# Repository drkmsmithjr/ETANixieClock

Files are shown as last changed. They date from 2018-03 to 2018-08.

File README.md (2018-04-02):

# [Estimated Time of Arrival (ETA) Nixie Tube Clock](http://surfncircuits.com/2018/04/01/what-is-an-eta-nixie-tube-clock-and-how-do-you-build-one)
This DIY project will combine the estimated time of arrival function with a nixie tube display to create an estimated time of arrival (ETA) Nixie tube clock. It is all easily controlled by a Raspberry Pi Zero W that is connected to the internet through WiFi to provide the latest time and gets the ETA for any number of destinations. The travel time is provided by the free Google Directions API interface that includes traffic to give the best estimates on any particular day.   The goal is that with an ETA Nixie tube clock, no math is needed to add a rough, often optimistic travel time, to the actual time to determine if we are running late.   The clock does that for you and with the power of IOT, is much more accurate!    A motion sensor is also added to the clock to turn off the Nixie Tube Display when no one is around, saving power and increasing the nixie tube lifetime.    The complete project, including the six IN-4 Nixie tubes, are powered from a 1 amp iPhone charger using the 5v to 170v Nixie Tube Power supply described in another repository. 

See [www.surfncircuits.com](http://surfncircuits.com/2018/04/01/what-is-an-eta-nixie-tube-clock-and-how-do-you-build-one)  for a complete description.  This github repository contains the Kicad Schematic, Spice Simulation, Efficiency Calculations of the Estimated Time of Arrival (ETA) Nixie Tube Clock.   

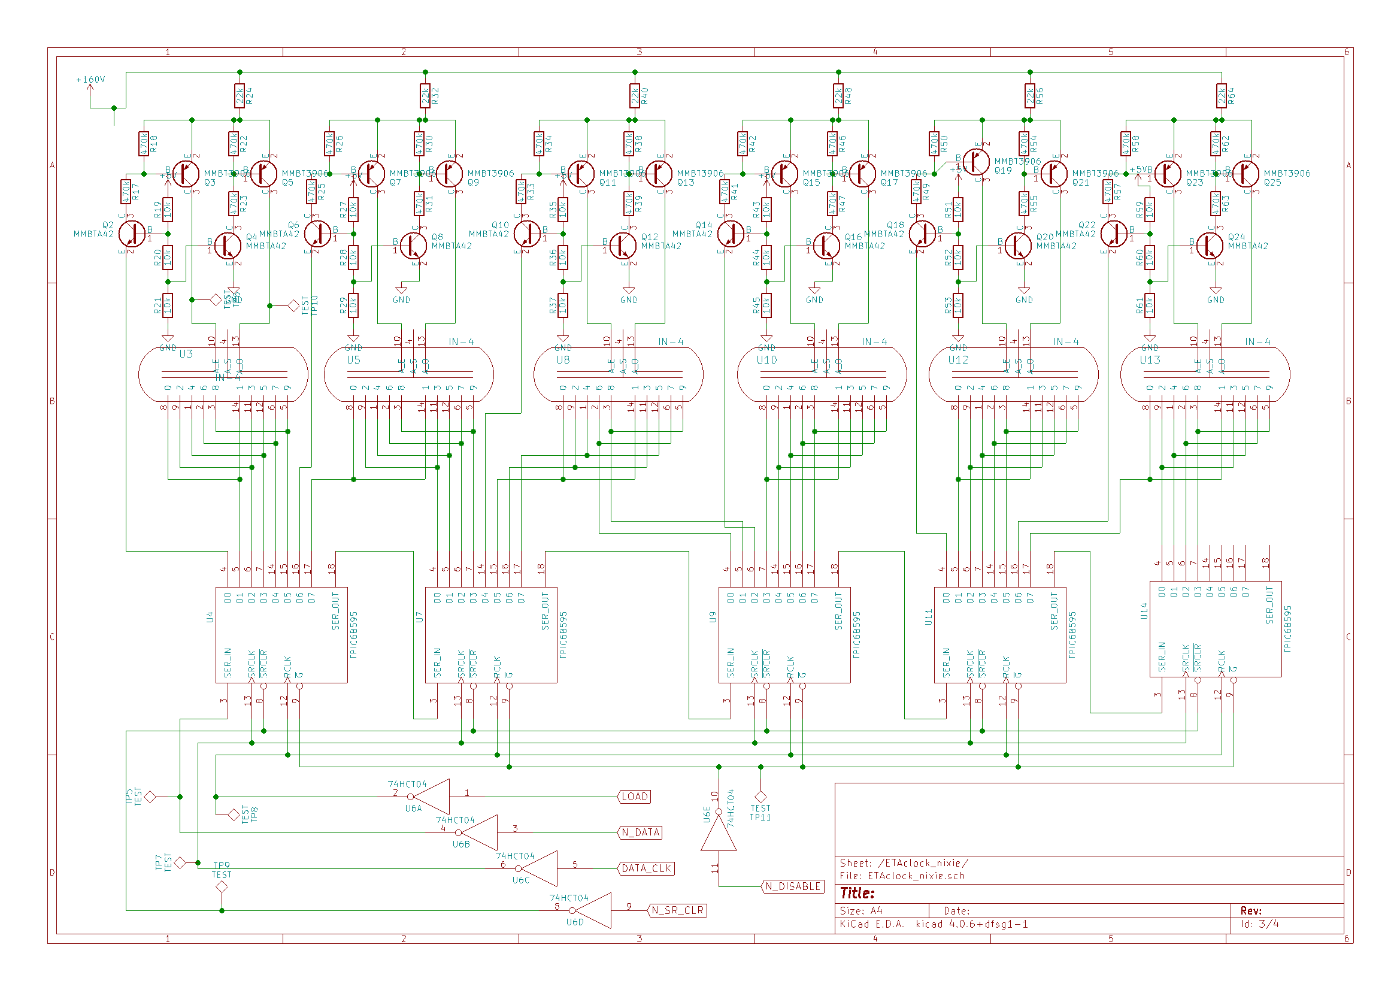
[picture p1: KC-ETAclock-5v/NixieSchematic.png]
PNG of the Schematic


__ETANixieCode__:  This is the python code that will be placed in the ETANixieClock directory on the Raspberry Pi zero.    

__KC_ETAclock-5v__:  KiCad schematic, PCB Layout, BOM of the ETA Nixie tube clock.  You can order the PCB from oshPark at   

__SimCalcFiles__:  Spice simulation files of the Nixie Tube bi-quinary driving circuit.    

__Datasheeets__: Datasheets for the pinout and the TPIC6B595.  In the Kicad Schematic, the part numbers and Digikey (TM) links are listed already.   Also the complete BOM is located in the KC-ETAclock-5v Directory (ETAclock_BOM.ods).      

See the complete blogs entry at  [www.surfncircuits.com](http://surfncircuits.com/2018/04/01/what-is-an-eta-nixie-tube-clock-and-how-do-you-build-one)

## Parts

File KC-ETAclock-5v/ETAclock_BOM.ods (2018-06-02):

Source: | /ETAclock.sch
Date: | Sat 03 Mar 2018 09:45:03 PM PST
Tool: | Eeschema 4.0.7-e2-6376~60~ubuntu17.10.1
Generator: | /usr/lib/kicad/plugins/bom_csv_grouped_by_value.py
Component Count: | 112
Collated Components:
Item | Qty | Reference(s) | Value | LibPart | Footprint | Datasheet | MPN
1 | 6 | C1, C2, C3, C4, C5, C6 | 0.1uF 250v | device:C | Capacitors_SMD:C_0805 | https://www.digikey.com/product-detail/en/tdk-corporation/CGA4J3X7T2E104M125AE/445-7965-1-ND/2782533 | CGA4J3X7T2E104M125AE
2 | 2 | C17, C19 | 47uF 10v | device:C | Capacitors_SMD:C_0805 | https://www.digikey.com/product-detail/en/taiyo-yuden/LMK212BBJ476MG-T/587-5465-1-ND/7067141 | LMK212BBJ476MG-T
3 | 6 | C23, C24, C25, C26, C27, C28 | 0.1uF | device:C | Capacitors_SMD:C_0805
4 | 6 | C29, C30, C31, C32, C33, C34 | 1uF | device:C | Capacitors_SMD:C_0805
5 | 4 | J1, J2, J3, J4 | Conn_01x01 | conn:Conn_01x01 | Mounting_Holes:MountingHole_2.2mm_M2_Pad
6 | 1 | J5 | USB_SUPPLY | ETAclock-rescue:USB_SUPPLY | etaclock:USB_SUPPLY_5v_TO_170v_MINI_2M
7 | 1 | J6 | Conn_01x05 | conn:Conn_01x05 | Pin_Headers:Pin_Header_Straight_1x05_Pitch2.54mm
8 | 1 | L1 | 60ohm 100Mhz | device:L | Resistors_SMD:R_0805 | https://www.digikey.com/product-detail/en/taiyo-yuden/BKP2125HS600-T/587-1932-1-ND/1465402 | BKP2125HS600-T
9 | 1 | P15 | Raspberry_PI_Zero_Hat | ETAclock-cache:Raspberry_PI_Zero_Hat | etaclock:R_Pi_Zero_40pins_No_Mount
10 | 12 | Q2, Q4, Q6, Q8, Q10, Q12, Q14, Q16, Q18, Q20, Q22, Q24 | MMBTA42 | transistors:MPSA42 | TO_SOT_Packages_SMD:SOT-23 | http://www.digikey.com/product-detail/en/micro-commercial-co/MMBTA42-TP/MMBTA42TPMSCT-ND/717401 | MMBTA42-TP
11 | 12 | Q3, Q5, Q7, Q9, Q11, Q13, Q15, Q17, Q19, Q21, Q23, Q25 | MMBTA92 | transistors:MPSA92 | TO_SOT_Packages_SMD:SOT-23 | http://www.digikey.com/product-detail/en/micro-commercial-co/MMBTA92-TP/MMBTA92-TPCT-ND/819693 | MMBTA92-TP
12 | 24 | R17, R18, R22, R23, R25, R26, R30, R31, R33, R34, R38, R39, R41, R42, R46, R47, R49, R50, R54, R55, R57, R58, R62, R63 | 470k | device:R | Resistors_SMD:R_0805
13 | 18 | R19, R20, R21, R27, R28, R29, R35, R36, R37, R43, R44, R45, R51, R52, R53, R59, R60, R61 | 10k | device:R | Resistors_SMD:R_0805
14 | 6 | R24, R32, R40, R48, R56, R64 | 22k | device:R | Resistors_SMD:R_0805
15 | 6 | U3, U5, U8, U10, U12, U13 | IN-4 | ETAclock-cache:IN-4 | etaclock:IN-4 | http://www.tube-tester.com/sites/nixie/data/in-4/in-4-sh1.htm
16 | 5 | U4, U7, U9, U11, U14 | TPIC6B595 | ETAclock-cache:TPIC5B595 | Housings_SOIC:SOIC-20W_7.5x12.8mm_Pitch1.27mm | http://www.digikey.com/product-detail/en/texas-instruments/TPIC6B595DWR/296-1351-1-ND/404964 | TPIC6B595DWR
17 | 1 | U6 | 74HCT04 | 74xx:74HCT04 | Housings_SOIC:SOIC-14_3.9x8.7mm_Pitch1.27mm | http://www.digikey.com/product-detail/en/fairchild-on-semiconductor/MM74HCT04MX/MM74HCT04MXCT-ND/965665 | MM74HCT04MX

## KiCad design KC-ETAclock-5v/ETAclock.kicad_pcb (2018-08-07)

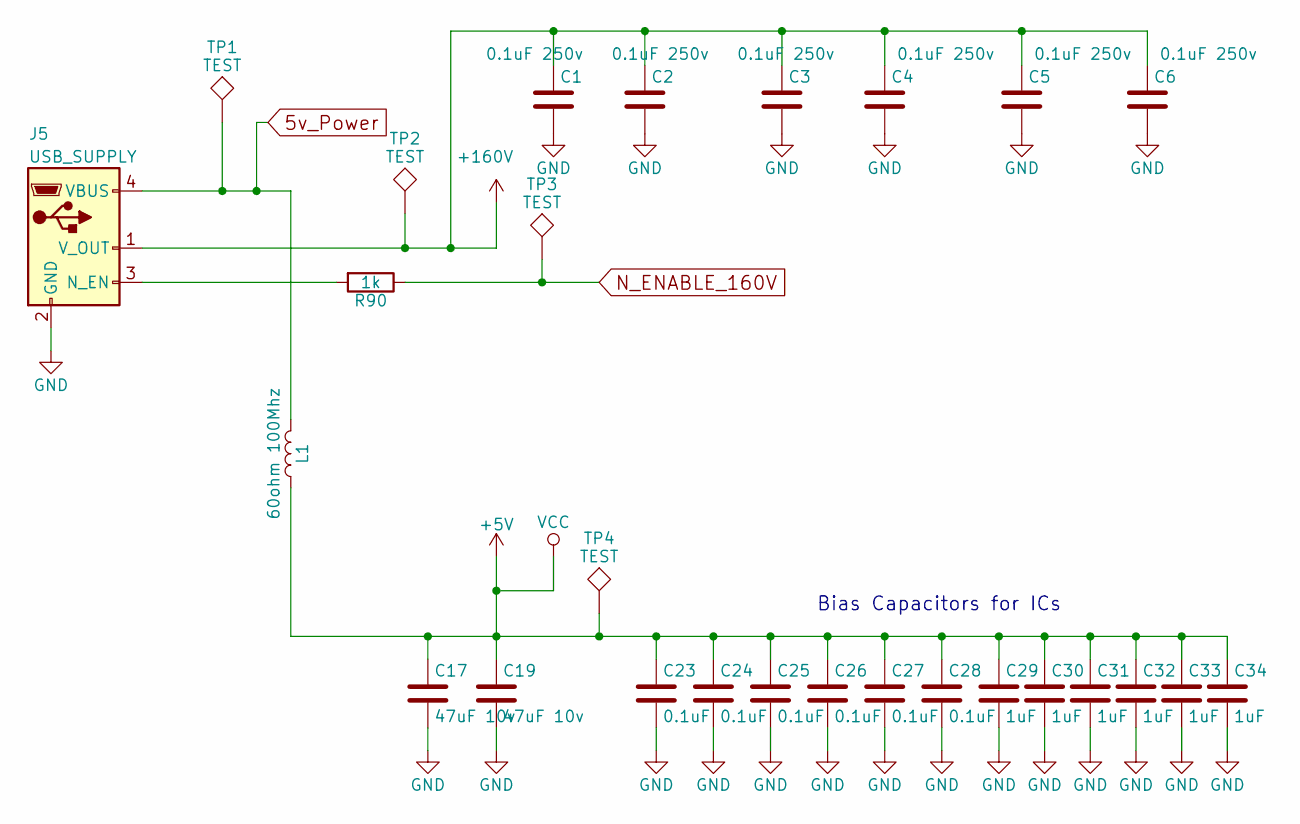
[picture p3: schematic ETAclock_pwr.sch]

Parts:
C1, C2, C3, C4, C5, C6: 0.1uF 250v; C_0805; MPN CGA4J3X7T2E104M125AE
C17, C19: 47uF 10v; C_0805; MPN LMK212BBJ476MG-T
C23, C24, C25, C26, C27, C28: 0.1uF; C_0805
C29, C30, C31, C32, C33, C34: 1uF; C_0805
J5: USB_SUPPLY; USB_SUPPLY_5v_TO_170v_MINI_2M
L1: 60ohm 100Mhz; R_0805; MPN BKP2125HS600-T
R90: 1k; R_0805
TP1, TP2, TP3, TP4: TEST; PINTST

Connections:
5v_Power: J5.4 (VBUS), L1.2, TP1.1
+5V: C17.1, C19.1, C23.1, C24.1, C25.1, C26.1, C27.1, C28.1, C29.1, C30.1, C31.1, C32.1, C33.1, C34.1, L1.1, TP4.1; also elsewhere on the board
+160V: C1.1, C2.1, C3.1, C4.1, C5.1, C6.1, J5.1 (V_OUT), TP2.1; also elsewhere on the board
GND: C1.2, C2.2, C3.2, C4.2, C5.2, C6.2, C17.2, C19.2, C23.2, C24.2, C25.2, C26.2, C27.2, C28.2, C29.2, C30.2, C31.2, C32.2, C33.2, C34.2, J5.2 (GND); also elsewhere on the board
N_ENABLE_160V: R90.1, TP3.1; also elsewhere on the board
unnamed: J5.3 (N_EN), R90.2

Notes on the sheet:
Bias Capacitors for ICs

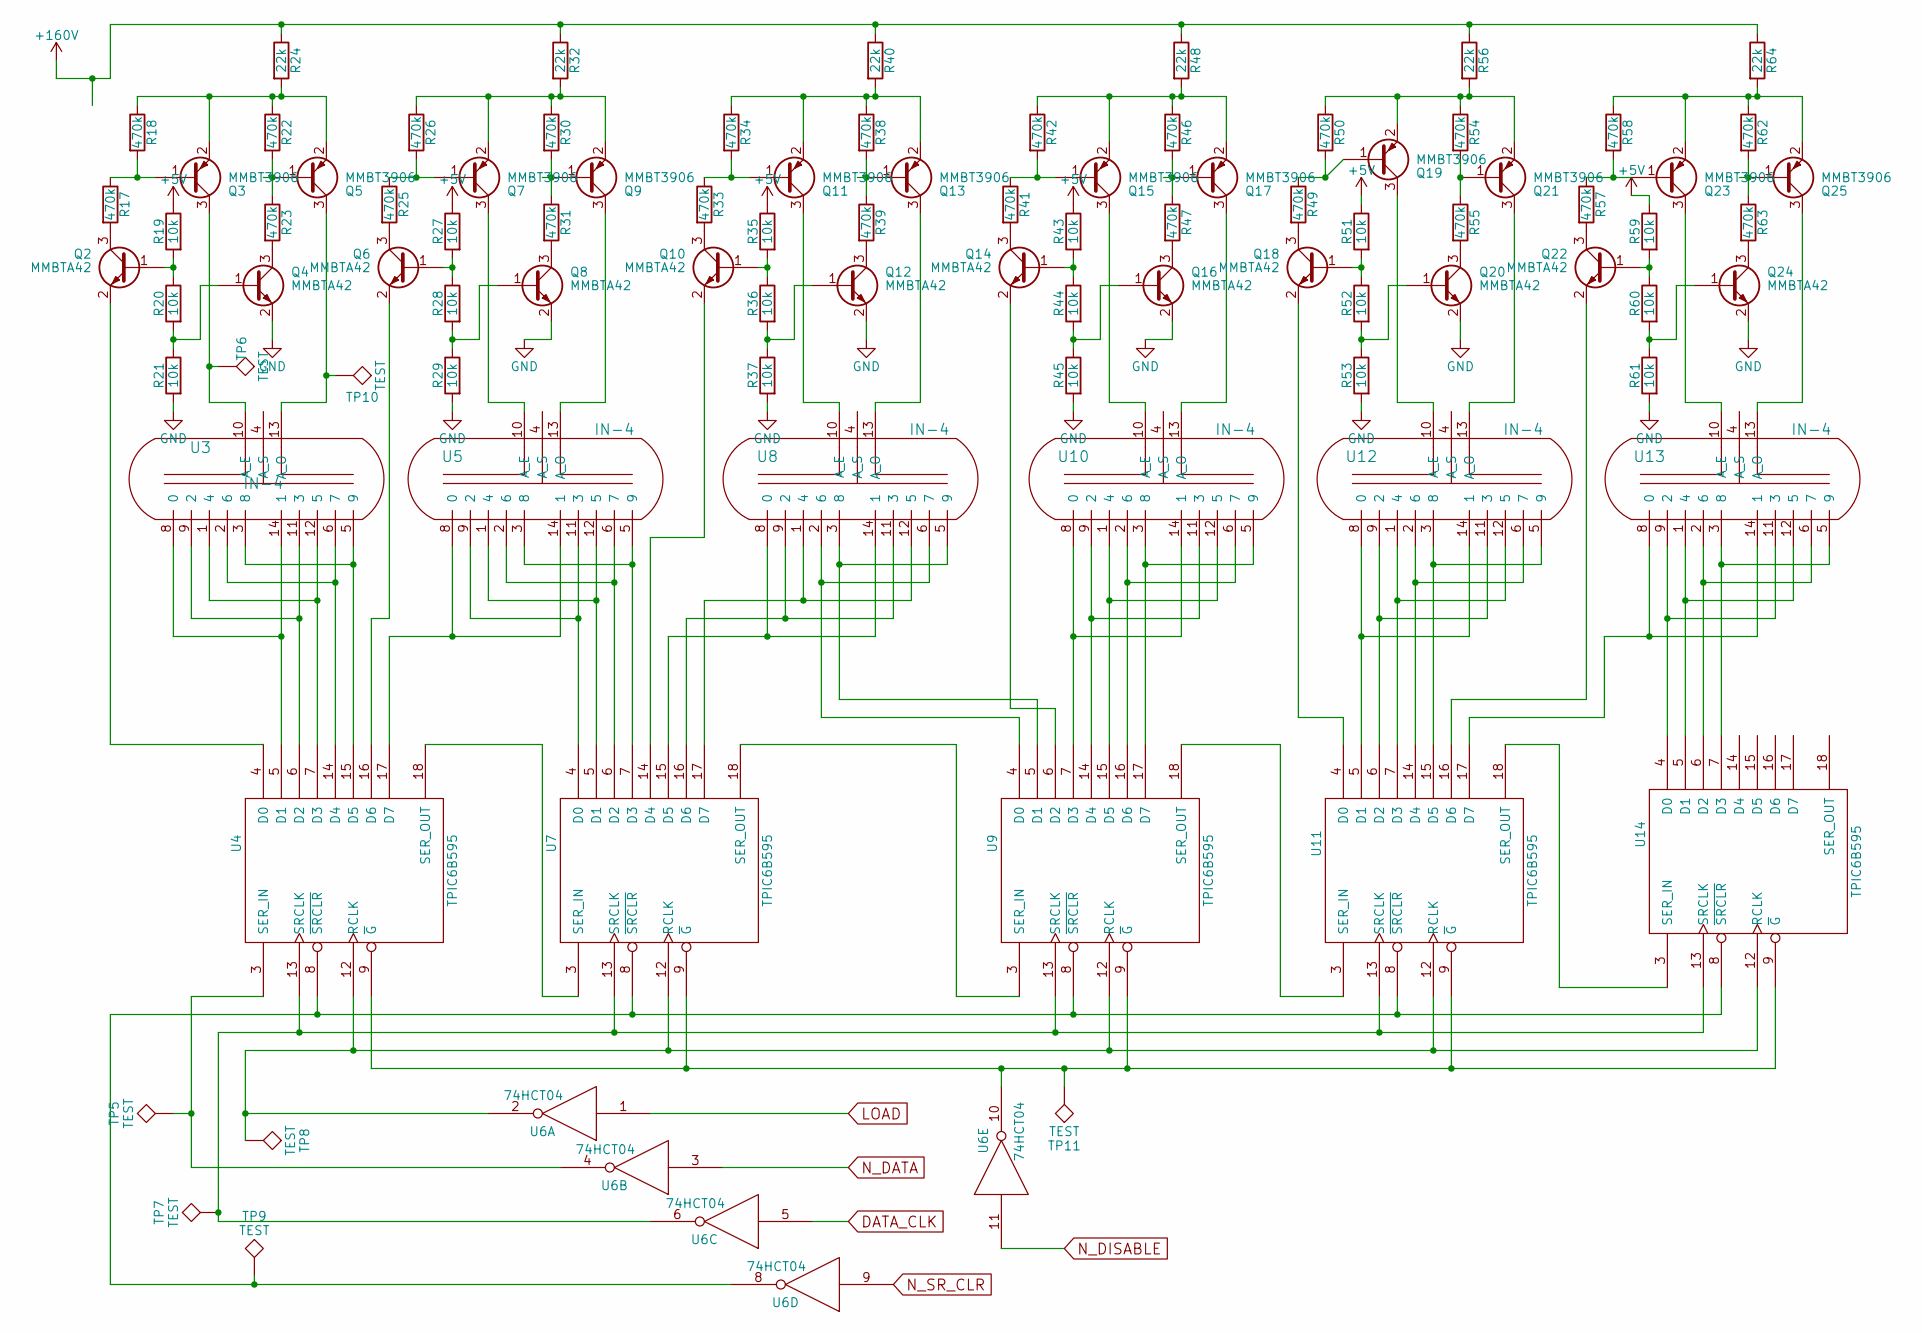
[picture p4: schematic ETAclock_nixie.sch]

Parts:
Q2, Q4, Q6, Q8, Q10, Q12, Q14, Q16, Q18, Q20, Q22, Q24: MMBTA42; SOT-23; MPN MMBTA42-TP
Q3, Q5, Q7, Q9, Q11, Q13, Q15, Q17, Q19, Q21, Q23, Q25: MMBT3906; SOT-23; MPN MMBTA92-TP
R17, R18, R22, R23, R25, R26, R30, R31, R33, R34, R38, R39, R41, R42, R46, R47, R49, R50, R54, R55, R57, R58, R62, R63: 470k; R_0805
R19, R20, R21, R27, R28, R29, R35, R36, R37, R43, R44, R45, R51, R52, R53, R59, R60, R61: 10k; R_0805
R24, R32, R40, R48, R56, R64: 22k; R_0805
TP5, TP6, TP7, TP8, TP9, TP10, TP11: TEST; PINTST
U3, U5, U8, U10, U12, U13: IN-4
U4, U7, U9, U11, U14: TPIC6B595; SOIC-20W_7.5x12.8mm_Pitch1.27mm; MPN TPIC6B595DWR
U6: 74HCT04; SOIC-14_3.9x8.7mm_Pitch1.27mm; MPN MM74HCT04MX

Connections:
+5V: R19.1, R27.1, R35.1, R43.1, R51.1, R59.1, U4.2 (VCC), U6.14 (VCC), U7.2 (VCC), U9.2 (VCC), U11.2 (VCC), U14.2 (VCC); also elsewhere on the board
+160V: R24.1, R32.1, R40.1, R48.1, R56.1, R64.1; also elsewhere on the board
DATA_CLK: U6.5; also elsewhere on the board
GND: Q4.2 (E), Q8.2 (E), Q12.2 (E), Q16.2 (E), Q20.2 (E), Q24.2 (E), R21.2, R29.2, R37.2, R45.2, R53.2, R61.2, U4.10 (GND), U4.11 (GND), U4.19 (GND), U6.7 (GND), U7.10 (GND), U7.11 (GND), U7.19 (GND), U9.10 (GND), U9.11 (GND), U9.19 (GND), U11.10 (GND), U11.11 (GND), U11.19 (GND), U14.10 (GND), U14.11 (GND), U14.19 (GND); also elsewhere on the board
LOAD: U6.1; also elsewhere on the board
N_DATA: U6.3; also elsewhere on the board
N_DISABLE: U6.11; also elsewhere on the board
N_SR_CLR: U6.9; also elsewhere on the board
unnamed: Q2.1 (B), R19.2, R20.1
unnamed: Q2.2 (E), U4.4 (D0)
unnamed: Q2.3 (C), R17.2
unnamed: Q3.1 (B), R17.1, R18.2
unnamed: Q3.2 (E), Q5.2 (E), R18.1, R22.1, R24.2
unnamed: Q3.3 (C), TP6.1, U3.10 (A_E)
unnamed: Q4.1 (B), R20.2, R21.1
unnamed: Q4.3 (C), R23.2
unnamed: Q5.1 (B), R22.2, R23.1
unnamed: Q5.3 (C), TP10.1, U3.13 (A_O)
unnamed: Q6.1 (B), R27.2, R28.1
unnamed: Q6.2 (E), U4.16 (D6)
unnamed: Q6.3 (C), R25.2
unnamed: Q7.1 (B), R25.1, R26.2
unnamed: Q7.2 (E), Q9.2 (E), R26.1, R30.1, R32.2
unnamed: Q7.3 (C), U5.10 (A_E)
unnamed: Q8.1 (B), R28.2, R29.1
unnamed: Q8.3 (C), R31.2
unnamed: Q9.1 (B), R30.2, R31.1
unnamed: Q9.3 (C), U5.13 (A_O)
unnamed: Q10.1 (B), R35.2, R36.1
unnamed: Q10.2 (E), U7.14 (D4)
unnamed: Q10.3 (C), R33.2
unnamed: Q11.1 (B), R33.1, R34.2
unnamed: Q11.2 (E), Q13.2 (E), R34.1, R38.1, R40.2
unnamed: Q11.3 (C), U8.10 (A_E)
unnamed: Q12.1 (B), R36.2, R37.1
unnamed: Q12.3 (C), R39.2
unnamed: Q13.1 (B), R38.2, R39.1
unnamed: Q13.3 (C), U8.13 (A_O)
unnamed: Q14.1 (B), R43.2, R44.1
unnamed: Q14.2 (E), U9.6 (D2)
unnamed: Q14.3 (C), R41.2
unnamed: Q15.1 (B), R41.1, R42.2
unnamed: Q15.2 (E), Q17.2 (E), R42.1, R46.1, R48.2
unnamed: Q15.3 (C), U10.10 (A_E)
unnamed: Q16.1 (B), R44.2, R45.1
unnamed: Q16.3 (C), R47.2
unnamed: Q17.1 (B), R46.2, R47.1
unnamed: Q17.3 (C), U10.13 (A_O)
unnamed: Q18.1 (B), R51.2, R52.1
unnamed: Q18.2 (E), U11.4 (D0)
unnamed: Q18.3 (C), R49.2
unnamed: Q19.1 (B), R49.1, R50.2
unnamed: Q19.2 (E), Q21.2 (E), R50.1, R54.1, R56.2
unnamed: Q19.3 (C), U12.10 (A_E)
unnamed: Q20.1 (B), R52.2, R53.1
unnamed: Q20.3 (C), R55.2
unnamed: Q21.1 (B), R54.2, R55.1
unnamed: Q21.3 (C), U12.13 (A_O)
unnamed: Q22.1 (B), R59.2, R60.1
unnamed: Q22.2 (E), U11.16 (D6)
unnamed: Q22.3 (C), R57.2
unnamed: Q23.1 (B), R57.1, R58.2
unnamed: Q23.2 (E), Q25.2 (E), R58.1, R62.1, R64.2
unnamed: Q23.3 (C), U13.10 (A_E)
unnamed: Q24.1 (B), R60.2, R61.1
unnamed: Q24.3 (C), R63.2
unnamed: Q25.1 (B), R62.2, R63.1
unnamed: Q25.3 (C), U13.13 (A_O)
unnamed: TP5.1, U4.3 (SER_IN), U6.4
unnamed: TP7.1, U4.13 (SRCLK), U6.6, U7.13 (SRCLK), U9.13 (SRCLK), U11.13 (SRCLK), U14.13 (SRCLK)
unnamed: TP8.1, U4.12 (RCLK), U6.2, U7.12 (RCLK), U9.12 (RCLK), U11.12 (RCLK), U14.12 (RCLK)
unnamed: TP9.1, U4.8 (~SRCLR), U6.8, U7.8 (~SRCLR), U9.8 (~SRCLR), U11.8 (~SRCLR), U14.8 (~SRCLR)
unnamed: TP11.1, U4.9 (~G), U6.10, U7.9 (~G), U9.9 (~G), U11.9 (~G), U14.9 (~G)
unnamed: U3.1 (4), U3.12 (5), U4.7 (D3)
unnamed: U3.2 (6), U3.6 (7), U4.14 (D4)
unnamed: U3.3 (8), U3.5 (9), U4.15 (D5)
unnamed: U3.9 (2), U3.11 (3), U4.6 (D2)
unnamed: U3.8 (0), U3.14 (1), U4.5 (D1)
unnamed: U4.17 (D7), U5.8 (0), U5.14 (1)
unnamed: U4.18 (SER_OUT), U7.3 (SER_IN)
unnamed: U5.1 (4), U5.12 (5), U7.5 (D1)
unnamed: U5.2 (6), U5.6 (7), U7.6 (D2)
unnamed: U5.3 (8), U5.5 (9), U7.7 (D3)
unnamed: U5.9 (2), U5.11 (3), U7.4 (D0)
unnamed: U7.15 (D5), U8.8 (0), U8.14 (1)
unnamed: U7.16 (D6), U8.9 (2), U8.11 (3)
unnamed: U7.17 (D7), U8.1 (4), U8.12 (5)
unnamed: U7.18 (SER_OUT), U9.3 (SER_IN)
unnamed: U8.2 (6), U8.6 (7), U9.4 (D0)
unnamed: U8.3 (8), U8.5 (9), U9.5 (D1)
unnamed: U9.15 (D5), U10.1 (4), U10.12 (5)
unnamed: U9.16 (D6), U10.2 (6), U10.6 (7)
unnamed: U9.17 (D7), U10.3 (8), U10.5 (9)
unnamed: U9.14 (D4), U10.9 (2), U10.11 (3)
unnamed: U9.7 (D3), U10.8 (0), U10.14 (1)
unnamed: U9.18 (SER_OUT), U11.3 (SER_IN)
unnamed: U11.5 (D1), U12.8 (0), U12.14 (1)
unnamed: U11.6 (D2), U12.9 (2), U12.11 (3)
unnamed: U11.7 (D3), U12.1 (4), U12.12 (5)
unnamed: U11.14 (D4), U12.2 (6), U12.6 (7)
unnamed: U11.15 (D5), U12.3 (8), U12.5 (9)
unnamed: U11.17 (D7), U13.8 (0), U13.14 (1)
unnamed: U11.18 (SER_OUT), U14.3 (SER_IN)
unnamed: U13.1 (4), U13.12 (5), U14.5 (D1)
unnamed: U13.2 (6), U13.6 (7), U14.6 (D2)
unnamed: U13.3 (8), U13.5 (9), U14.7 (D3)
unnamed: U13.9 (2), U13.11 (3), U14.4 (D0)

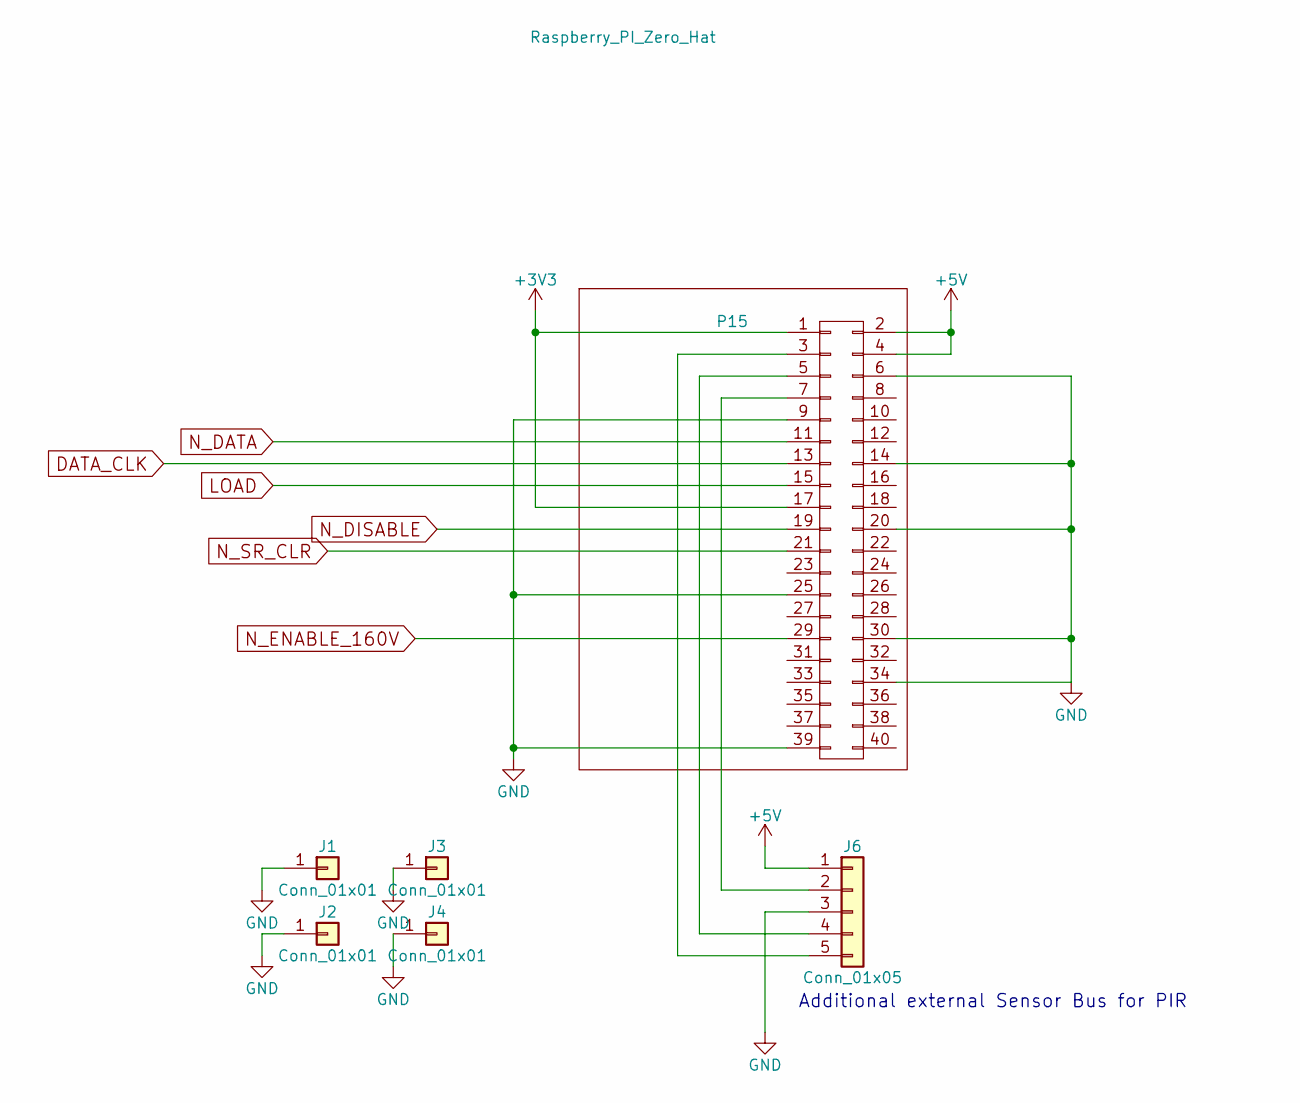
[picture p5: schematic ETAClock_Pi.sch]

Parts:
J1, J2, J3, J4: Conn_01x01; MountingHole_2.2mm_M2_Pad
J6: Conn_01x05; Pin_Header_Straight_1x05_Pitch2.54mm
P15: Raspberry_PI_Zero_Hat; R_Pi_Zero_40pins_No_Mount

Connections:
+3V3: P15.1, P15.17
+5V: J6.1, P15.2, P15.4; also elsewhere on the board
DATA_CLK: P15.13; also elsewhere on the board
GND: J1.1, J2.1, J3.1, J4.1, J6.3, P15.6, P15.9, P15.14, P15.20, P15.25, P15.30, P15.34, P15.39; also elsewhere on the board
LOAD: P15.15; also elsewhere on the board
N_DATA: P15.11; also elsewhere on the board
N_DISABLE: P15.19; also elsewhere on the board
N_ENABLE_160V: P15.29; also elsewhere on the board
N_SR_CLR: P15.21; also elsewhere on the board
unnamed: J6.2, P15.7
unnamed: J6.4, P15.5
unnamed: J6.5, P15.3

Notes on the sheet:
Additional external Sensor Bus for PIR

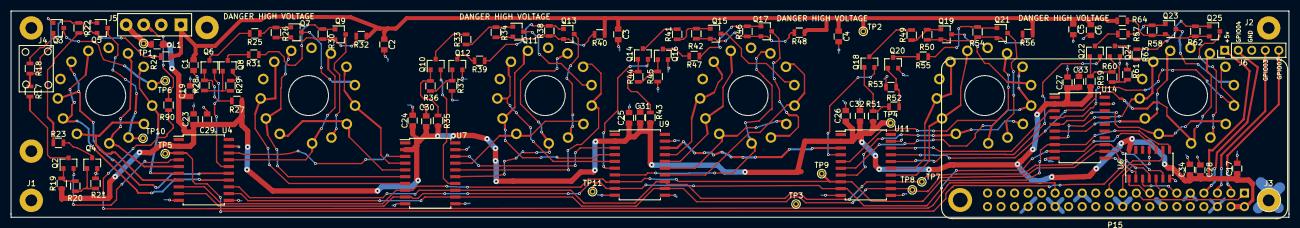
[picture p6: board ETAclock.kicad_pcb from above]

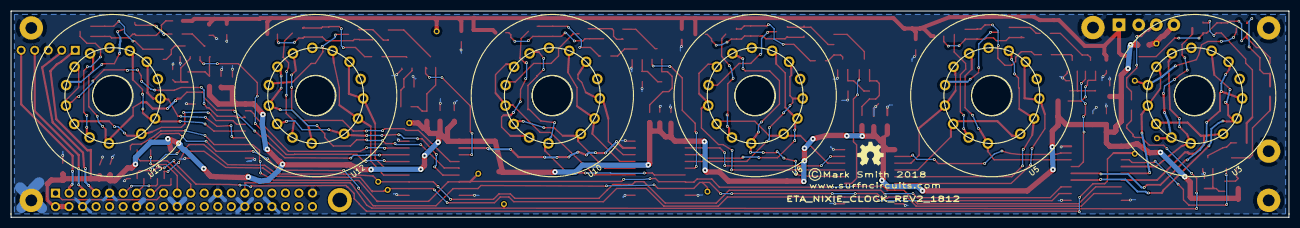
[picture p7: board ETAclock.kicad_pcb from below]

Board: 2 copper layers, 240.0 x 38.7 mm, 124 parts (6 on the bottom side), 114 nets.

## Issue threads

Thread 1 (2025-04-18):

Request

jet438, 2025-04-18:
Good Morning Mark: Sorry if this isn't the correct place to do this. I'm interested in this project on a number of levels. Very interested. I'm wanting to build a Nixie clock on an RPI base that serves as both a clock and a count down timer to a given day and time...namely retirement.. I'd like to do that utilizing In-12 tubes (because I already have them). I read your blog and noted the electrical difference between the Nixie you used and the ones I have. Unfortunately, my skills aren't in electrical schematic design or component choices. Those things are WAY out of my league. I'm a Civil Engineer...a "Grog make fire" kinda guy when it comes these type of things. That said, I can solder rather well and I do follow instructions extremely well.
In your blog you noted at one point that you were contemplating an additional schematic utilizing the In-14. Being very similar to the In-12 I'm curious as to whether you completed that design both on the schematic and python program levels since the registers (?) would have to change.
Anyway just wondering what or if there is an ETA for it.

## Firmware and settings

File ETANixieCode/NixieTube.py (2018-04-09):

#!/usr/bin/python
import RPi.GPIO as GPIO
import math
import time
import threading

# the tubes are architected to be a serial bit stream input.  
# the nixie type is for different types of Nixies

# BCM GPIP pin numbers being used 
N_DATA = 17
DATA_CLK = 27
LOAD = 22
N_DISABLE = 10
N_SR_CLR = 9
N_EN_PowerSupply = 5
PIR_SENSE=4


class NixieTube():

   def __init__(self,nixietype = 'IN-4', elements = 1 , PIR_SENSOR = False):
        self.nixietype = nixietype
        self.elements = elements
        # the displayed Digits to keep track of current state.  Initially empty
        # digits and StoredDigits will be a array of integers representing the digits to be displayed
        

        self.StoredDigits = []
        # the data that will be transferred to update the display
        self.SerialData = []
        for x in range (0,self.elements):
           self.StoredDigits.append(0)
        #setup GPIO to use the BCM numbering.  The adufruit extension shows the BCM 
        # BCM numbering
        GPIO.setmode(GPIO.BCM)   
        # set warnings false to avoid generating errors when the channel was set already
        GPIO.setwarnings(False)
        # intially set N_data high so data is low    
        GPIO.setup(N_DATA,GPIO.OUT, initial=GPIO.HIGH)
        # Data gets shifted in on the falling edge of DATA_CLK
        GPIO.setup(DATA_CLK,GPIO.OUT, initial=GPIO.LOW)
        # The LOAD will transfer shift registers to storge registers on falling edge of LOAD
        GPIO.setup(LOAD,GPIO.OUT , initial=GPIO.LOW)
        # NDISABLE: keeping this low will keep all outputs off on IC 
        self.DISPLAY_ON = False
        GPIO.setup(N_DISABLE,GPIO.OUT , initial=GPIO.LOW)
        # When Low shift registers are transferred to storage registers
        GPIO.setup(N_SR_CLR,GPIO.OUT , initial=GPIO.LOW)
        self.register_clear()
        # pulling low will ENABLE power supply
        self.POWER_ON = False
        GPIO.setup(N_EN_PowerSupply,GPIO.OUT , initial=GPIO.HIGH)
        # set the PIR_SENSE to an input and if the NixieTube has PIR_SENSOR..
        # PIR_SENSOR can also be used to turn on/off the PIR_SENSOR operation
        # Default of PIR_SENSOR is False
        # Default of the PIR_SENSE = True... ensure the clock will turn on
        self.PIR_SENSOR = PIR_SENSOR
        #self.PIR_SENSOR = True
        self.PIR_SENSE = True
        # PIR delay is in minutes
        self.PirDelay = 1
        GPIO.setup(PIR_SENSE,GPIO.IN)
        # define the sampling rate and delays for the PIR sensor in seconds 
        # the PIR sensor has a delay of 4 seconds.  so every 3 seconds will ensure to capture event
        self.PirSampling = 1
        self.CurrentDelay = 0
        # start the thread to sample the PIR Sensor
        self.PirSampleThread = threading.Thread(target = self.PirSample, args = (self.PirSampling,self.PirDelay))
        self.PirSampleThread.daemon = True 
        self.PirSampleThread.start()
              

   def PirSample(self,PirSampling,PirDelay):
        # this routine will run in a thread
        # if the PIR_SENSOR is On/ACTIVE, it will test the input
        # it will sample the PIR sensor every PirSampling rate
        # and it will update the PIR_SENSE boolean solution
        next_call = time.time()
        while self.PIR_SENSOR:
           #test PIR_SENSE input.
           self.CurrentDelay += PirSampling
           #print(self.CurrentDelay)
           if GPIO.input(PIR_SENSE):
              self.CurrentDelay = 0
           if self.CurrentDelay > (PirDelay*60):
              self.PIR_SENSE = False
              self.Power_Off()
              #clamp the currentDelay to max value
              self.CurrentDelay = PirDelay*60+1
           else:
              self.PIR_SENSE = True
           print(self.PIR_SENSE,self.CurrentDelay,GPIO.input(PIR_SENSE))
           next_call = next_call + PirSampling
           time.sleep(next_call - time.time())
                
   def digitsToSerial (self,digits,BlankCntrl = []):
        # this routine will conver the digits into the correct serial string.       
        # digits is an array that has at least # elemnts in it.
        # each digit will be converted into 6 serial bits.
        # bit 6 is even or odd (1 for even, 0 for odd)
        # the other 5 bits are zero except for the displayed digits
        # (ODD/EVEN BIT, 0-1,2-3,4-5,6-7, MSB = 8-9)
        # BlankCntrl is an optional parameter
        # that allows easy blanking of one digit in string
        # It will be an array of Booleans that correspond to the digits array
        # True for display, False for Blanking of that digit (not display)
        # for 12h time, the first digit is often not displayed.
        # test is BlankCntrl is empty, then default to display all 
        if len(BlankCntrl) == 0:
           for x in range (0, self.elements):
              BlankCntrl.append(True)       
        #Resetting serial data
        self.SerialData = []
        for x in range (0,self.elements):
           # find the digit numbering
           dignum = math.floor(digits[x]/2.0)
           # convert this into a power of two + 1  
           sdata = int(2**(dignum+1))
           # test to see if we should blank this displayed.  TRUE mean display digit 
           if BlankCntrl[x] == True:
              # bit wise OR with bin(64) or 7 sigit binary so we can perform bitwise ops
              sdata = sdata | 0b1000000
           else:
              #ensure all data is zero bits,2,3,4,5,6.   7th bit will be still even or odd and set.    
              sdata = 0b1000000
           # test for EVEN or ODD.  If EVEN, then LSB = 1
           if digits[x] % 2.0 == 0:
              sdata = sdata | 0b1
           # perform an exclusive or to get NDATA
           sdata = sdata ^ 0b111111
           strdata = bin(sdata)
           # now put the binary into array of 0 or 1 integers.  Ignore first 3 characters
           # these characters will be 0b1 from above
           for x in range (3,9):
              self.SerialData.append(int(strdata[x]))
        #print(self.SerialData)
        
   def ShiftData(self):
     # this will shift the SerialData into the serial registers
     # the data is loaded, then the data_clk goes high then low to clock in 
        for x in self.SerialData:
           GPIO.output(N_DATA, x)
           self.data_clock()
        GPIO.output(N_DATA,GPIO.HIGH)   
           
   def data_clock(self):
        GPIO.output(DATA_CLK,GPIO.HIGH)
        time.sleep(.001)         
        GPIO.output(DATA_CLK,GPIO.LOW)
        
   def LoadData(self):
        GPIO.output(LOAD,GPIO.HIGH)
        time.sleep(.001)         
        GPIO.output(LOAD,GPIO.LOW)  
        
   def register_clear(self):
        GPIO.output(N_SR_CLR,GPIO.HIGH)
        time.sleep(.001)         
        GPIO.output(N_SR_CLR,GPIO.LOW)
        
   def Display_On(self):
        if self.DISPLAY_ON == False:
           GPIO.output(N_DISABLE,GPIO.HIGH)
           self.DISPLAY_ON = True
   
   def Display_Off(self):
        if self.DISPLAY_ON:
           GPIO.output(N_DISABLE,GPIO.LOW)
           self.DISPLAY_ON = False
           time.sleep(.001)     

   def Power_On(self):
        if self.POWER_ON == False and self.PIR_SENSE:
        #if self.POWER_ON == False:
           GPIO.output(N_EN_PowerSupply,GPIO.LOW)
           self.POWER_ON = True 
           time.sleep(0.100)    

   def Power_On_Nodelay(self):
        if self.POWER_ON == False and self.PIR_SENSE:
        #if self.POWER_ON == False:
           GPIO.output(N_EN_PowerSupply,GPIO.LOW)
           self.POWER_ON = True 
           time.sleep(0.100)     
           
   def Power_Off(self):
        if self.POWER_ON:
           GPIO.output(N_EN_PowerSupply,GPIO.HIGH)
           self.POWER_ON = False
           time.sleep(.001)     

   def Write_Display(self, digits, BlankCntrl = []):
        self.Power_On()
        self.digitsToSerial(digits, BlankCntrl)
        self.register_clear()
        self.ShiftData()
        self.Display_Off()
        self.LoadData()
        self.Display_On()

   def Write_Display_No_Off(self, digits, BlankCntrl = []):
        self.Power_On()
        self.digitsToSerial(digits, BlankCntrl)
        self.register_clear()
        self.ShiftData()
        #self.Display_Off()
        self.LoadData()
        self.Display_On()
        self.StoredDigits = digits

   def Write_Spin_Digits(self, z, BlankCntrl = [], spin = 10):
        # Will take the current digits (z) and spin them in place for 
        # spin times .
        # there is a delay=2ms between displays
        # the total time for the spin is going to be write_display * spin.   
        delay = .002
        # power on the display if it is off.   
        self.Power_On()
        for y in range (0,spin):
          #increment z and reset to zero if reach 10
          for g in range (0,len(z)):
             z[g] += 1   
             if z[g] > 9:
                z[g] = 0
          self.Write_Display(z,BlankCntrl)
          time.sleep(delay)

   def Write_Spin_To_Digits(self, orig_digits, new_digits, orig_BlankCntrl = [], new_BlankCntrl = [], startspin = 5, transpin = 3):
        # Will take the current digits (z) and spin them in place and 
        # then start to display the new digits one at a time for number of total elements
        # the startspin is number of spins before starting
        # the transpins is the spins during transitions.
        # there is a delay=2ms between displays
        # the total time for the spin is going to be write_display * spin.   
        delay = .002
        # power on the display if it is off.   
        self.Power_On()

        orig_digitsCpy = list(orig_digits)
        orig_BlankCntrlCpy = list(orig_BlankCntrl)
        ind_digits = []
        ind_BlankCntrl = []

        # we need to use blank cntrl in this routine
        if orig_BlankCntrl == []:
           orig_BlankCntrlCpy = [True]*len(orig_BlankCntrl)

        if new_BlankCntrl == []:
           new_BlankCntrl = [True]*len(new_BlankCntrl)

        
        # spin then all now 
        for y in range (0,startspin):
          #increment z and reset to zero if reach 10
          for g in range (0,len(orig_digitsCpy)):
             orig_digitsCpy[g] += 1   
             if orig_digitsCpy[g] > 9:
                orig_digitsCpy[g] = 0
          self.Write_Display(orig_digitsCpy,orig_BlankCntrlCpy)
          time.sleep(delay)

        # now fix the first new digit and spin the rest of them
        for y in range(0,len(new_digits)):
          # add one to ind_digits
          # pop one from top of orig_digits
          ind_digits.append(new_digits[y])
          ind_BlankCntrl.append(new_BlankCntrl[y])
          orig_digitsCpy.pop(0)
          orig_BlankCntrlCpy.pop(0)
          # spin just the original digits fixing the rest
          for x in range (0,transpin):
          #increment z and reset to zero if reach 10
             for g in range (0,len(orig_digitsCpy)):
                orig_digitsCpy[g] += 1   
                if orig_digitsCpy[g] > 9:
                   orig_digitsCpy[g] = 0
             self.Write_Display(ind_digits+orig_digitsCpy,ind_BlankCntrl+orig_BlankCntrlCpy)
             time.sleep(delay)

          # update the ind_digits with the new BlankCntrl
          # now spin the original digits


   def Write_Fade_Out_Fade_In(self, digits, BlankCntrl = []):
        #print("digits into functions")
        #print(digits)
        self.Power_On()
        Tperiod = .0075   
        Cycles = 30
        #print(self.StoredDigits)
        #Fade OUt
        for x in range (0,Cycles):
           self.Display_On()
           time.sleep(Tperiod*(Cycles-x-1)/Cycles)
           self.digitsToSerial(self.StoredDigits, BlankCntrl)
           self.register_clear()
           self.ShiftData()
           self.LoadData()
           self.Display_Off()
           time.sleep(Tperiod*(x+1)/Cycles)
        #Fade In
        Cycles = 20
        for x in range (0,Cycles):
           self.Display_Off() 
           time.sleep(Tperiod*(Cycles-x-1)/Cycles)
           self.digitsToSerial(digits,BlankCntrl)
           self.register_clear()
           self.ShiftData()
           self.LoadData()
           self.Display_On()
           time.sleep(Tperiod*(x+1)/Cycles)
        self.digitsToSerial(digits, BlankCntrl)
        self.register_clear()
        self.ShiftData()
        self.LoadData()
        self.Display_On()
        self.StoredDigits = digits
        #print("stored digits")
        #print(digits)

   def Write_Fade_Out(self):
        # Fade_Out will take the StoredDigits and Fade it out.
        # Tperiod is the Period of on and off
        # cycles is how many cycles to make up the period.   
        # Tperiod*Cycles is the total transition time 
        self.Power_On()
        Tperiod = .0075   
        Cycles = 30
        print(self.StoredDigits)
        #Fade OUt
        for x in range (0,Cycles):
           self.Display_On()
           time.sleep(Tperiod*(Cycles-x-1)/Cycles)
           self.digitsToSerial(self.StoredDigits, BlankCntrl)
           self.register_clear()
           self.ShiftData()
           self.LoadData()
           self.Display_Off()
           time.sleep(Tperiod*(x+1)/Cycles)

   def Write_Fade_In(self, digits, BlankCntrl = []):
        # Fade_Out will take the StoredDigits and Fade it out.
        # Tperiod is the Period of on and off
        # cycles is how many cycles to make up the period.   
        # Tperiod*Cycles is the total transition time
        self.Power_On()
        Tperiod = .0075   
        Cycles = 20
        print(self.StoredDigits)
        #Fade OUt
        
        #Fade In
        for x in range (0,Cycles):
           self.Display_Off() 
           time.sleep(Tperiod*(Cycles-x-1)/Cycles)
           self.digitsToSerial(digits, BlankCntrl)
           self.register_clear()
           self.ShiftData()
           self.LoadData()
           self.Display_On()
           time.sleep(Tperiod*(x+1)/Cycles)
        self.digitsToSerial(digits, BlankCntrl)
        self.register_clear()
        self.ShiftData()
        self.LoadData()
        self.Display_On()
        self.StoredDigits = digits

   def Write_In_Fade_Out(self, digits, BlankCntrl = []):
        # Fade_Out will take the StoredDigits and Fade it out.
        # Tperiod is the Period of on and off
        # cycles is how many cycles to make up the period.   
        # Tperiod*Cycles1 + Tperiod*Cycles2 is the total transition time 
        self.Power_On()
        Tperiod = .0010   
        Cycles = 20
        print(self.StoredDigits)
        for x in range (0,Cycles):
           self.digitsToSerial(digits, BlankCntrl)
           self.register_clear()
           self.ShiftData()
           self.LoadData()
           self.Display_On()
           time.sleep(Tperiod*(x+1)/Cycles)
           self.digitsToSerial(self.StoredDigits,BlankCntrl)
           self.register_clear()
           self.ShiftData()
           self.LoadData()
           self.Display_On()
           time.sleep(Tperiod*(Cycles - x-1)/Cycles)
        self.digitsToSerial(digits, BlankCntrl)
        self.register_clear()
        self.ShiftData()
        self.LoadData()
        self.Display_On()
        self.StoredDigits = digits


   def Ramp_Display(self,digits, BlankCntrl = []):
   # turn on the nixie tube while ramping supply
        self.Power_Off()
        time.sleep(.125)
        self.digitsToSerial(digits, BlankCntrl)
        self.register_clear()
        self.ShiftData()
        self.Display_Off()
        self.LoadData()
        self.Display_On()
        for x in range(0,10):
           self.Power_On_Nodelay()
           time.sleep(.02)
           self.Power_Off
           time.sleep(.01)
        self.Power_On_Nodelay()
        time.sleep(.05)
        self.StoredDigits = digits
        
   def Pir_Sensor_On(self):
        self.PIR_SENSOR = True    
   
   def Pir_Sensor_Off(self):
        self.PIR_SENSOR = False

   def Pir_Delay_set(self,minutes):
        self.PirDelay = minutes    

  
if __name__ == "__main__":
        print "hello world"
       
        x = NixieTube()
        #x.Power_On()
        #for y in range (0,10):
        #   x.digitsToSerial([y])
        #   print(y,x.SerialData)
        #   x.ShiftData()
        #for y in range (0,10):
        #   x.data_clock()
        #for y in range (0,10):
        #   x.LoadData()
        #for y in range (0,10):
        #   x.register_clear()
        #for y in range (0,10):
        #   x.Display_On()
        #   x.Display_Off()
        #x.Write_Display([8])
        #time.sleep(0.5)
        #x.Write_Display([9])
        #time.sleep(0.5)       
        #x.Display_Off()
        y = 0
        z = 0

        while True:
           z += 1
           try:
              time.sleep(.02)
              x.Write_Display([y])
              y += 1
              if y > 9:
                  y = 0
              if z > 200:
                  break 
           except:
              time.sleep(0.2)
              x.Display_Off()
        x.Display_Off()
        x.Power_Off()
        

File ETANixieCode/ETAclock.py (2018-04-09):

#!/usr/bin/python

from locations import dest,orig
from googlemapsclientkey import clientkey
import NixieTube

import googlemaps
import datetime 
import math

import time
from time import sleep
from threading import Timer

# this timer will sychronize to system time time.time().   Great for clocks
class RepeatedSyncTimer(object):
  def __init__(self, interval ,function, *args, **kwargs):
    self._timer = None
    self.interval = interval
    self.function = function
    self.args = args
    self.kwargs = kwargs
    self.is_running = False
    self.error = 0.0
    # set this so that the interval is at 50% 0f a second, for clock to update
    # only needed if we have seconds
    self.next_call = math.ceil(time.time()) + 0.5
    self.start()

  def _run(self):
    self.is_running = False
    self.start()
    self.function(*self.args,**self.kwargs)

  def start(self):
    if not self.is_running:
      #syncronize the interval to 50% to allow to account for errors in the timer.
      #the timer interval is adjusted to sychronize with real time.  
      # this is important for clocks.  Above this was set at 50% of the interval
      self.next_call += self.interval
      self._timer = Timer(self.next_call - time.time(), self._run)
      self._timer.start()
      self.is_running = True

  def stop(self):
    self._timer.cancel()
    self.is_running = False

# in this algorithm.  print the time first, followed by each of the destinations 
# in the Array in order.

def PrtTime(timestr):
    global ind
    global TravelDuration
    global dest
    global TravelDurText
    # transtime determine how long in seconds to display the current ETA or Current time.  
    transtime = 5
    now = datetime.datetime.now()
    seconds = int(now.strftime("%S"))
    seconds = seconds % 10
    DigitSec.Write_Display([seconds])
    #print(seconds)
    # use the mod command to loop through all the destinations and print one at a time. 
    # we can use other functions and sequences to follow different activities.  
    ind2 = int(math.floor(ind/transtime))
    if ind2 >= len(dest):
       print(str(now)+ " " +  "The Current Time " + str(now))
       ind += 1
       if ind2 > len(dest):
          ind = 0
    else:
       ETA = now + datetime.timedelta(seconds=TravelDuration[ind2]) + datetime.timedelta(minutes=ETDdelay)
       print(str(now) + " "+ dest[ind2]['toplace'] + " " + str(ETA) + " Travel Time: " + TravelDurText[ind2])
       ind += 1

def PrtCurrentTimeOneNixie(timestr):
    global ind
    global TravelDuration
    global dest
    global TravelDurText
    # transtime determine how long in seconds to display the current ETA or Current time.  
    now = datetime.datetime.now()
    seconds_1digit = int(now.strftime("%S"))
    seconds_1digit = seconds_1digit % 10
    #DigitSec.Write_Display([seconds_1digit])
    Hour = int(now.strftime("%I"))
    Hour_1digit = int(math.floor(Hour/10.0))
    Hour_2digit = Hour % 10  
    Minute = int(now.strftime("%M"))
    Minute_1digit = int(math.floor(Minute/10.0))
    Minute_2digit = Minute % 10
    time_digits= [Hour_1digit,Hour_2digit,Minute_1digit,Minute_2digit]
    # test is we have twenty four hour time
    
    if ind > 4:
       ind = 0
    if ind == 4:
       z = time_digits[3]
       #DigitSec.Write_Fade_Out()
       time.sleep(.05)
       for y in range (0,10):
          z+=1
          if z > 9:
             z = 0
          DigitSec.Write_Display([z,z,z,z,z,z])
          time.sleep(.0075)
       DigitSec.Display_Off() 
    else:
       #DigitSec.Display_Off()
       #time.sleep(0.02)
       #DigitSec.Ramp_Display([time_digits[ind]])
       #DigitSec.Write_Display([time_digits[ind]])
       if ind == 0:
          #DigitSec.Write_Fade_In([time_digits[ind],time_digits[ind]])
          DigitSec.Write_Display([time_digits[ind],time_digits[ind],time_digits[ind],time_digits[ind],time_digits[ind],time_digits[ind]])
       else:
          #DigitSec.Write_Fade_Out_Fade_In([time_digits[ind],time_digits[ind]])
          DigitSec.Write_Display([time_digits[ind],time_digits[ind],time_digits[ind],time_digits[ind],time_digits[ind],time_digits[ind]])
       print(str(now), time_digits, time_digits[ind])
    ind += 1

def PrtCurrentTimeSixNixie(timestr):
    global ind
    global TravelDuration
    global dest
    global TravelDurText
    global pre_time_digits
    global pre_BlankCntrl

    # how many time to display current time before spin
    time_series = 5
    # after displaying time, provide a spin
    # then display all the locations for this amount of time each (in seconds)
    location_series = 4
    # flow description
    # 1. first time_series seconds, display the time
    # 2. spin display at end of time
    # 3. present each location for location_series seconds (location number, blank, four digits)
    # 3.5 spin at each change of location.   
    # 4. repeat at 1
 
    # transtime determine how long in seconds to display the current ETA or Current time.  
    now = datetime.datetime.now()
    # test to determine if we should be using a ETA
    #print("ind")
    #print(ind)
    ind3 = 0

    if ind-time_series > 0: 
       ind3 = math.floor((ind-time_series) / location_series/1.0)
       ind3 = int(ind3)
       #print("ind3")
       if ind3 >= len(TravelDuration):
          ind3 = len(TravelDuration)-1
       #print(ind3)
       now = now + datetime.timedelta(seconds=TravelDuration[ind3]) + datetime.timedelta(minutes=ETDdelay)
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

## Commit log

2018-03-10 Version 1 of the ETA Nixie Tube Clock. This version was ordered from OshPark March 3rd.
    [ETAClock_Pi.sch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]
2018-03-15 New V2 of Layout to Fix Nixie Tube radius offset and the Nixie tube pin 3 placement. It is suppose to be at 49 degree C instead of 43 degree c.
    Code was updated to add Fade In and Fade Out commands. Also Code updated to
    Add an option for a PIR sensor. The PIR Sensor code is working.
    [ETAclock.kicad_pcb]
2018-04-01 New Layout changes. Fixed the BJT packages. Added 1k to the 160v_enable pin to protect the rasberry pi. Improved the 160v spacing to the power supply input.
    updated the code with both a testscript and a testETAclock.py to help test the code.
    [ETAclock-B.Cu.gbl, ETAclock-B.Mask.gbs, ETAclock-B.SilkS.gbo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]
2018-04-02 LInk to Oshpark board
2018-06-02 The PCB was updated to show FAB lines through the NIXIE tubes so a print copy can be used to make a drill template for the nixie tube cutout.
    The Bom formatting was updated for easy printout.
    [ETAclock.kicad_pcb, ETAclock_BOM.ods]
2018-06-03 Created a new TestDigits.py program to test the Nixie Digits one a time every Three Seconds. This will help to identify if there is any issue with the tubes.
    [TestDigits.py]
2018-08-07 The TestDigits.py is a script file that allows for the following feastures:
    - cycle through all digits 1 second at a time
    - display any single digit
    - burn in all digits
    - burn in even digits
    - burn in odd digits
    - toggle N_DISABLE
    - toggle POWER
    here is the command from the python script.
    print("press:")
    print("return: to index the displayed diget to the next value")
    print("[t]: to start time 1-9:")
    print("[T]: For a x minute burn in of all digits")
    print("[0-9]: to display the digit to light up")
    print("[d]: to toggle display N_DISABLE")
    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
    [ETAclock.kicad_pcb, ETAclock_nixie.sch]
2018-08-16 The testdigits.py script now has more options to help test and debug the nixie tubes. Great for fixing cathode poisoning and for getting all six tubes to work together.
    [TestDigits.py]
